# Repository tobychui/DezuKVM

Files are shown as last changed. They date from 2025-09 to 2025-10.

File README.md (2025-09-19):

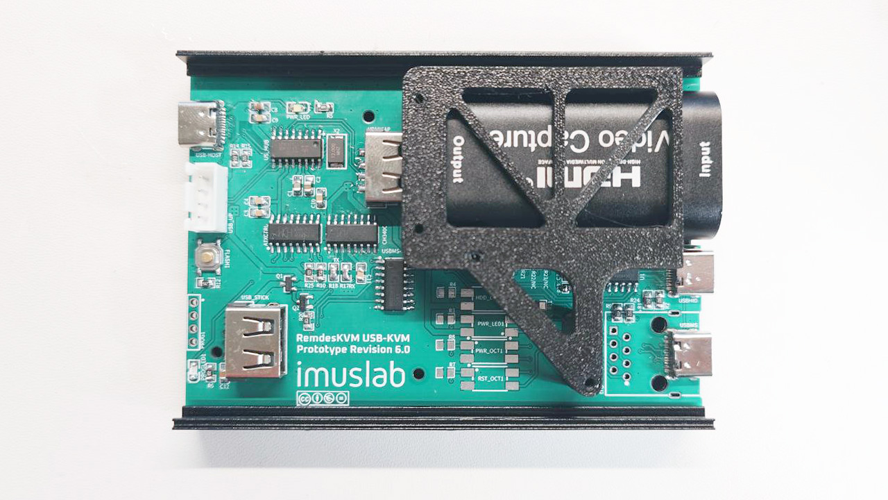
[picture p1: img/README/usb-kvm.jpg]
usb-kvm


# RemdesKVM

Budget IP-KVM designed for my SFF homelab / minilab setup.  I build this just because I don't really trust those off-the-shelf KVMs and Pi-KVM is a bit too expensive if I want to have one KVM device per computer in my homelab cluster. 

> [!WARNING]
> This project is in its very early stage and not production ready. Use with your own risk. 

## Build

### Remdeskd (RemdesKVM daemon)

The Remdeskd is a golang written piece of code that runs on a x86 or ARM computer with Debian based Linux installed. Require v4l2 and alsa with kernel 6.1 or above.  

To build the Remdeskd, you will need go compiler. The go package manager will take care of the dependencies during your first build. 

```bash
cd remdeskd/
go mod tidy
go build

sudo ./remdeskd
# or use ./remdeskd -h to show all start options
```

(Setup the remdeskd as systemd service instruction will be added later)

#### Uskvm (IP-KVM firmware)

The usbkvm is developed with Arduino IDE. You will need the [ch55xduino broad API](https://github.com/DeqingSun/ch55xduino) installed in order to compile and flash the firmware to the USB-KVM hardware.

For first time flashing the firmware, **follow the steps below carefully**.

1. Prepare the firmware code in your Arduino
2. Press compile button and wait for the compiled binary get cached (to speed up the flash process)
3. Hold down the FLASH button on the USB-KVM PCB. **Do not release it until you are told to do so.**
4. Insert the USB cable into the USB-KVM host side port and connect it to your computer. You should see multiple device pops up in your device manager. If all parts are soldered correctly, you will see a USB hub with 3 devices under it, the USB capture card (which provide a video and audio device file), a USB to UART adapter and an unknown device. That Unknown device is our CH552g (without firmware)
5. Press the upload button in your Arduino IDE with no serial port selected
6. **Just after the code compiled, immediately release the FLASH button** (Notes: if you do this too slow, you will get a timeout in your Arduino IDE console. If you release too early, the MCU will reset itself and back to runtime mode. Try a few time if you keep having issues with this step)
7.  After the firmware upload, you should see a Serial device pop up in your device manager and the unknown device is gone. 

For future firmware re-flash or update, simply upload using the serial port like an ordinary Arduino dev board. 

## Architecture

The RemdesKVM project divides into two subsystems

1. IP-KVM Host software (running on x86 / ARM computer with USB host port)
2. USB-KVM Hardware and firmware (connect to KVM-host using USB)

Each of the parts can be used independently with or without the other part of the system.  For example, you can use the IP-KVM Host software with off-the-shelf USB-KVM that uses the same chipset used in the RemdesKVM USB-KVM device, or you can use the USB-KVM hardware and firmware on a Raspberry Pi with other KVM host software (with limited functionality). 

### Project Structure

- models -- 3D models files for 3D printing
- pcbs -- PCB gerber and schematics 
- remdeskd -- RemdesKVM Daemon, running on the IP-KVM host ARM SBC
- usbkvm -- Firmware for RemdesKVM USB-KVM on board MCU (Ch552g)

**Note: There will be no support if you are using 3rd party parts or systems. If you are creating a new issue, make sure you are using the official implementation here with the recommended hardware and software setups**

### Part List

## Change Log

Change log for USB-KVM hardware design

| Version | Changes | Issues |
| --- | --- | --- |
| v1.0 - v2.0 | Concept prototypes | - |
| v3.0 | Reduce complexity | HDMI child board not working |
| v4.0 | Restructure board form factor | CH552G do not handle UART signal fast enough for cursor movements |
| v5.0 | Added USB mass storage port and dedicated USB UART chip for UART to HID chip communication | USB mass storage power switch causes overcurrent on USB VBUS line and resets the whole bus |

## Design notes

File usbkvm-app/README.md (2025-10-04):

# USB-KVM App

A USB-KVM application that runs on your laptop / PC that provide an interface for using the USB-KVM device.

**This is the off-grid version of DezuKVM and only provide a subset of features that the full DezuKVM IP-KVM has to offer. This is mostly for local debugging or as a temporary display / keyboard & mouse for server management. **

## Hosting

### Self-hosted Site with HTTPS

Since the USB-KVM app is simply a webpage, if you already got a server with proper HTTPS setup, you can just rename & place the whole `./www/` folder into your web server and launch the index.html on your laptop that has the USB-KVM device connected. 

### Run USB-KVM App Offline / Without external web server

If you do not have a HTTPS web server already running in your homelab or you want to use the USB-KVM offline, you can use the simple HTTPS server provided here to serve the site wit ha self-signed certificate.

```
go mod tidy
go build
./usbkvm
```

This will automatically generate the `cert.pem` and `key.pem` file for the TLS connection and you can visit the self-hosted USB-KVM App user interface by opening `https://localhost:8443` using Chrome (or any Chromium based) browser.

*Note: Firefox do not support Web Serial API, so until Firefox support this API, you will not be able to use this with Firefox Browser.*

## Usage

1. Connect the DezuKVM USB-KVM device to your laptop via the host side USB port
2. Connect the remote server / computer that you want to control to the DezuKVM USB-KVM device via the HDMI port and the USB port. 
3. Start USB-KVM app on your laptop. Since all the operations and logic are written on the front-end page, you can either load it from a remote or local web server, as soon as there are **HTTS** it will work.
4. Select the video capture device, it usually shows up as USB Video
5. (Optional) Select the audio capture device, it usually show up as USB Digital Audio
6. Click the keyboard icon and select the USB UART interface that connects to the CH9329 keyboard HID chip. There are two serial devices on the DezuKVM device and the USB UART one are for KVM and the CDC device are for the onboard auxiliary MCU (the AuxMCU is not used in this setup. See dezukvmd for more details on how it is used)
7. If everything works correctly, you should be able to see your remote computer video and audio output on your browser tab, as well as moving the remote cursor with your local mouse.

## Screenshots

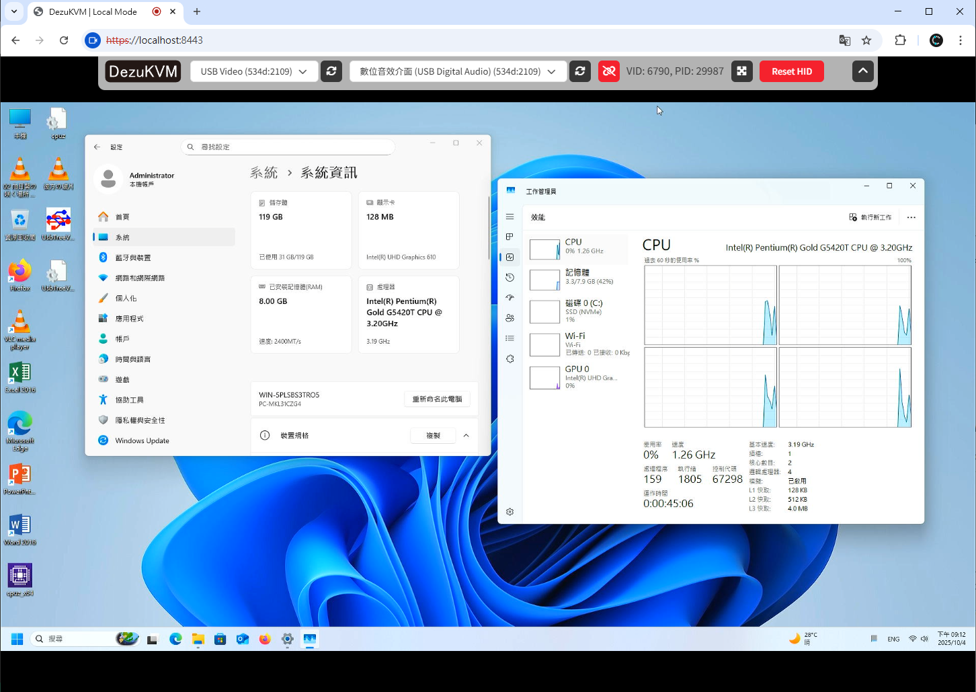
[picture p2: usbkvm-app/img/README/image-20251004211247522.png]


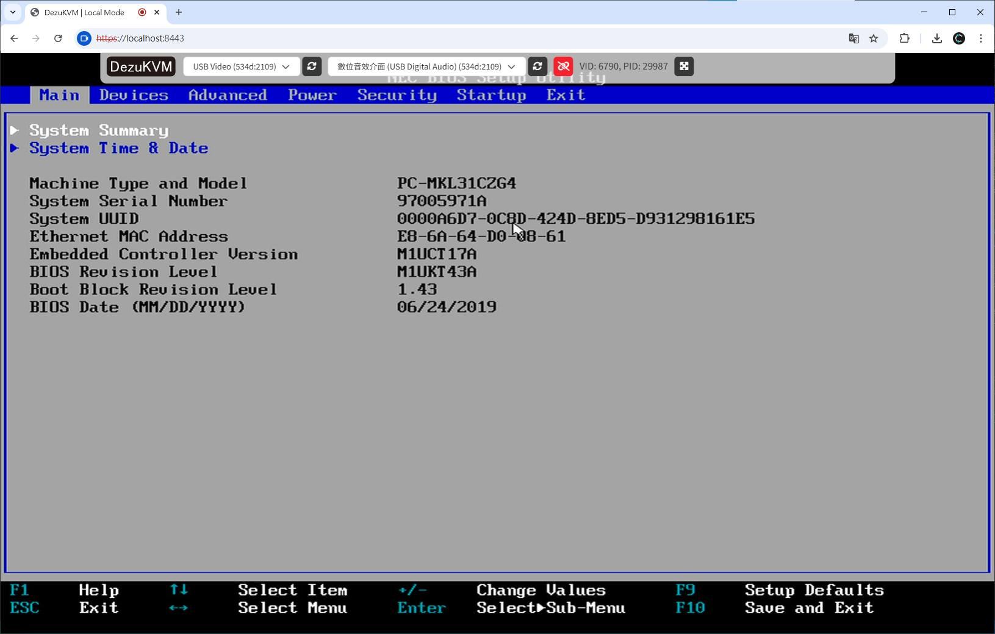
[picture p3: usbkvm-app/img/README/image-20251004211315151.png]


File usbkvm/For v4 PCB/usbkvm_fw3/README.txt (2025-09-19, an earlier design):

By default the CH9329 uses 9600 baudrate to communicate with MCU
However, this might significantly reduce the fps of the cursor
If you want a smoother cursor experience, follow the steps below to configure
the CH9329 to use a higher baudrate to communicate with CH552G

1. Flash the CH552G with Serial0 9600 baudrate to act as a USB to UART converter
2. Plug in the CH9239 port to your slave computer so it get power
3. Use the remdeskvmd -mode=cfgchip command to set the baudrate to 19200
4. Disconnect the CH9329 KVM port that also power down the CH9329
5. Flash the CH552G with Serial0 updated to 19200 baudrate
6. Repower the CH9329, now CH552G shd be able to communicate with it using 19200 baudrate

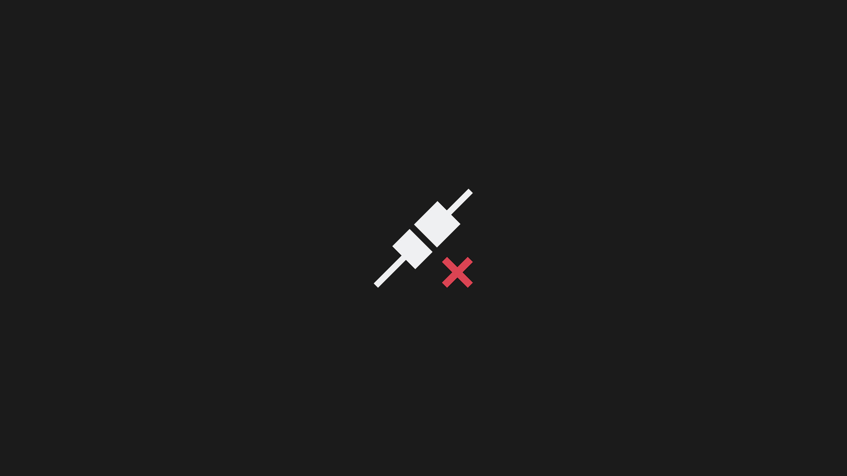
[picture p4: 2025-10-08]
dezukvmd/mod/usbcapture/stream_takeover.jpg

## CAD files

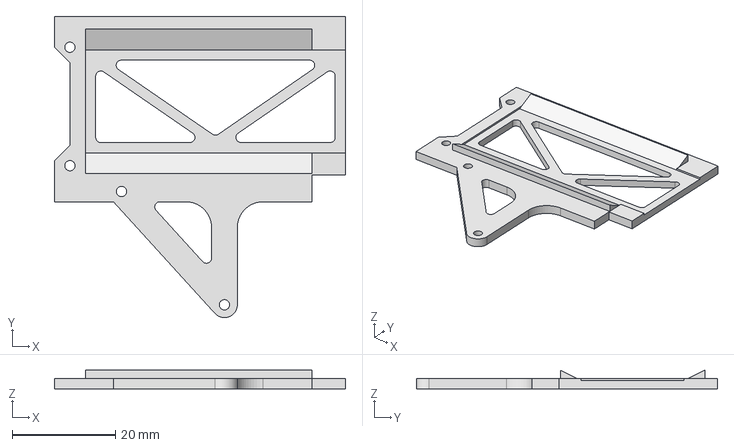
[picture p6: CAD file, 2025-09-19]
models/hdmi-capture-holder/capture_holder_bottom.stp
56.5 x 58.5 x 3.60 mm

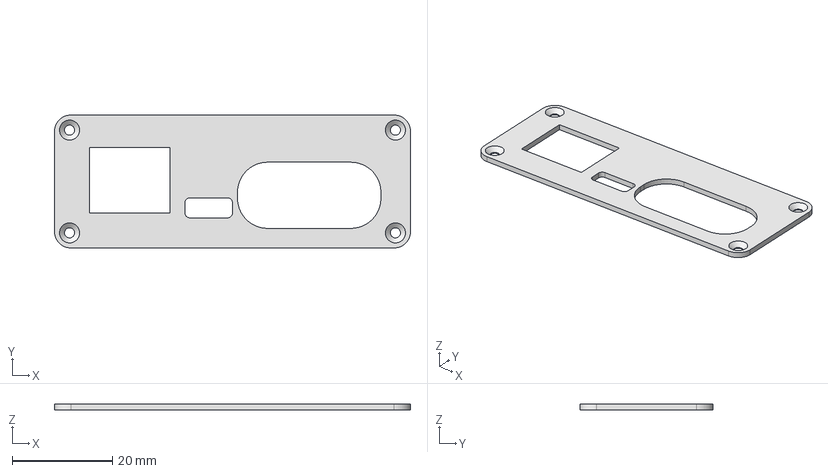
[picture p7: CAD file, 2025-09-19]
models/usb-kvm-case/cover-slave.stp
71.0 x 26.5 x 1.20 mm

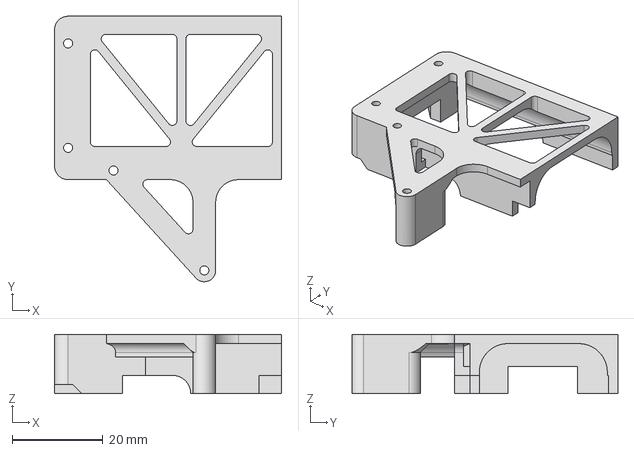
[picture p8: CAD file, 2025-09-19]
models/hdmi-capture-holder/capture_holder_top.stp
50.0 x 58.5 x 13.0 mm

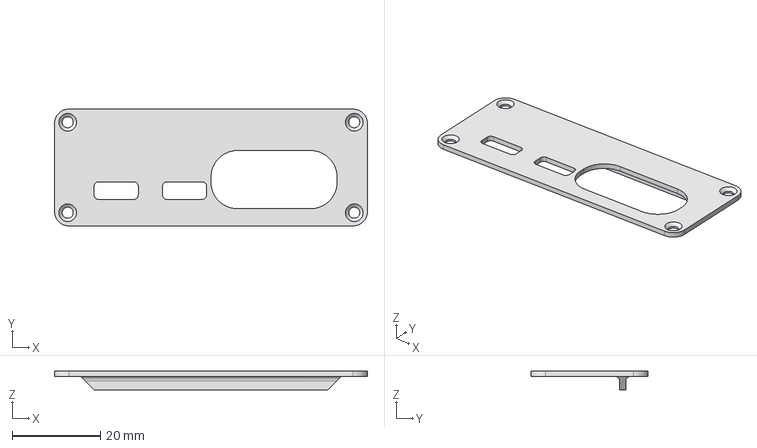
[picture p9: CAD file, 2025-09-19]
models/usb-kvm-case/cover-slave-usbms.stp
71.0 x 26.5 x 4.20 mm

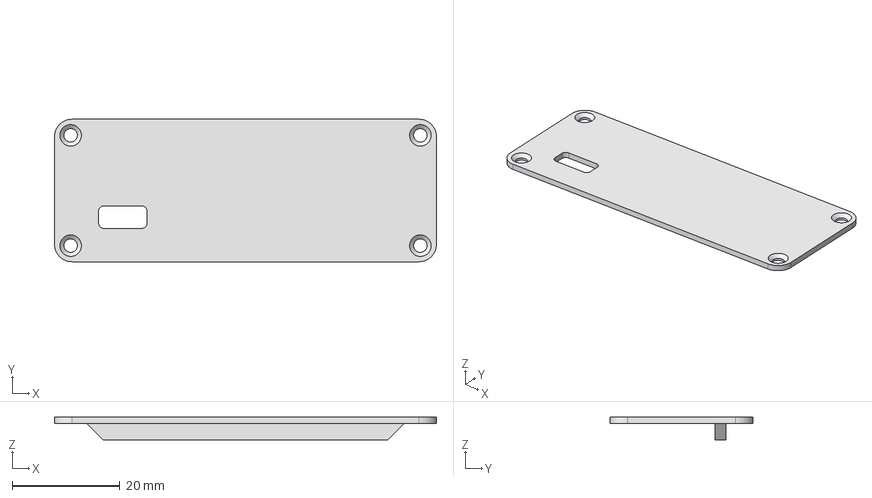
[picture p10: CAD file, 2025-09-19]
models/usb-kvm-case/cover.stp
71.0 x 26.5 x 4.20 mm

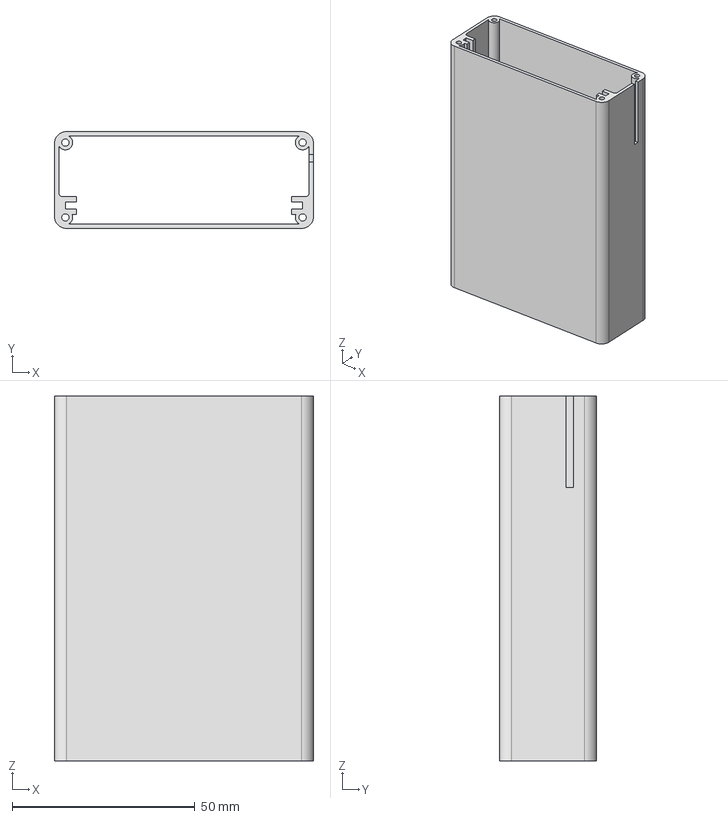
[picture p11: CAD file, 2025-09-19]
models/usb-kvm-case/case.stp
71.0 x 26.5 x 100.0 mm

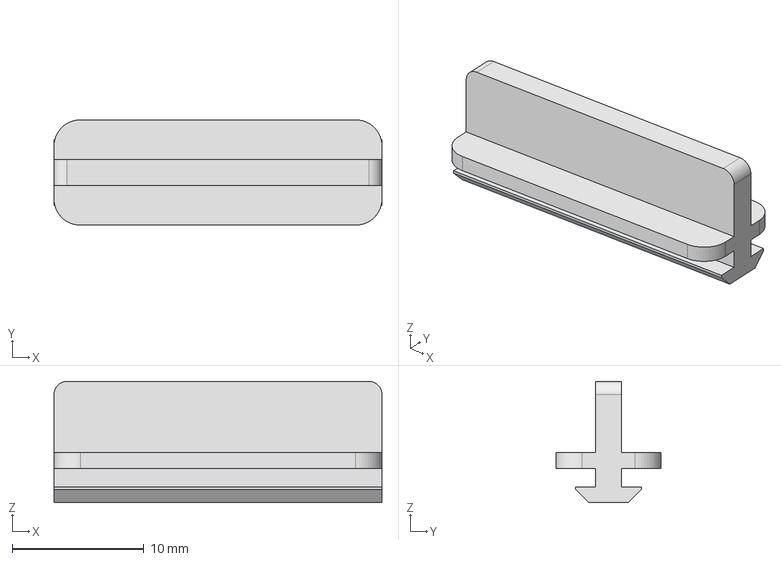
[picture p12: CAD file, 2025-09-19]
models/usb-kvm-case/flag.stp
24.9 x 8.00 x 9.20 mm

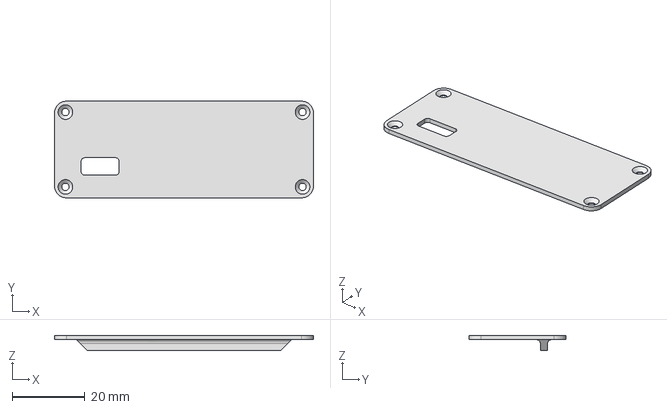
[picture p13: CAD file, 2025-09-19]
models/usb-kvm-case/cover-usb-ms.stp
71.0 x 26.5 x 4.20 mm

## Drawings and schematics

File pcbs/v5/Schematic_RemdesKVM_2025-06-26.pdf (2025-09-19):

## Upstream USB Port Power Ripple Filter

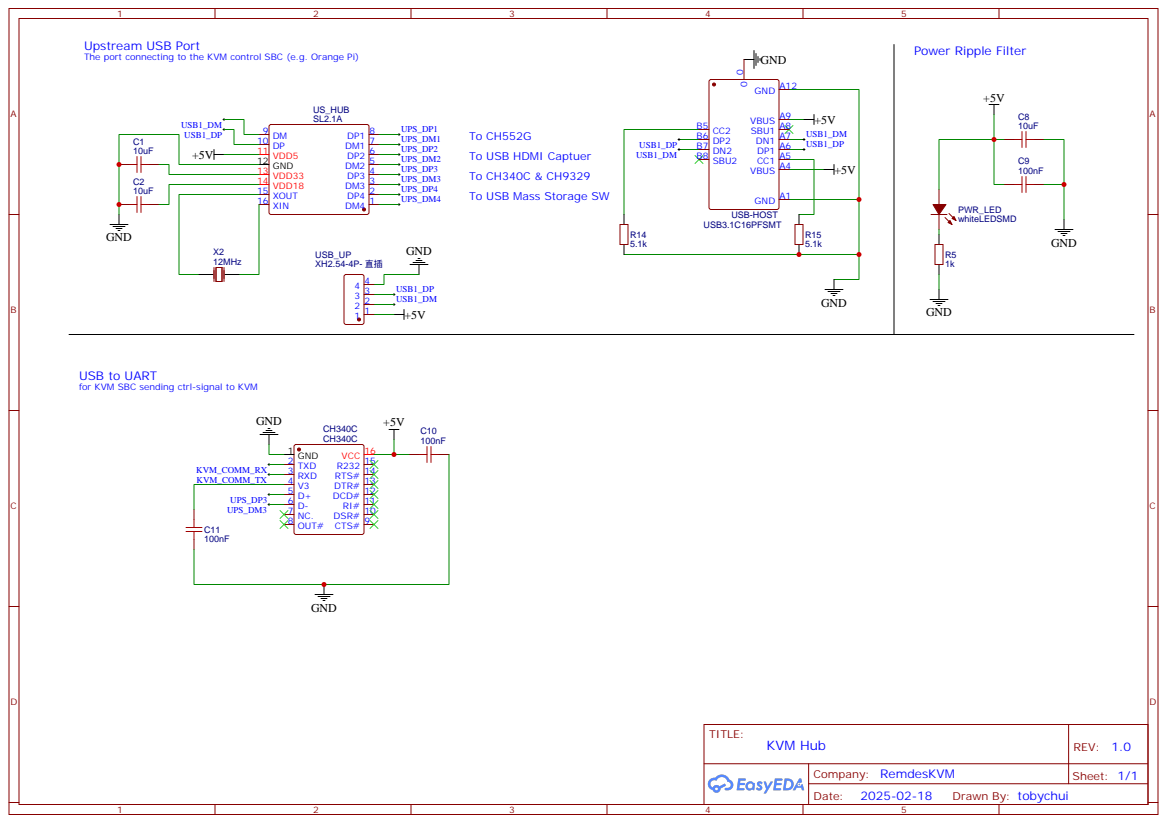
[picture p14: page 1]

The port connecting to the KVM control SBC (e.g. Orange Pi)

To USB HDMI Captuer
To USB Mass Storage SW

USB to UART
for KVM SBC sending ctrl-signal to KVM

DSR# 10 RI# 11 DCD# 12 DTR# 13 RTS# 14 R232 15 VCC 16

## USB HDMI Capture Card

# DEF 10 SET 11 UD+ 12 UD- 13 GND 14 VCC 15 V33 16

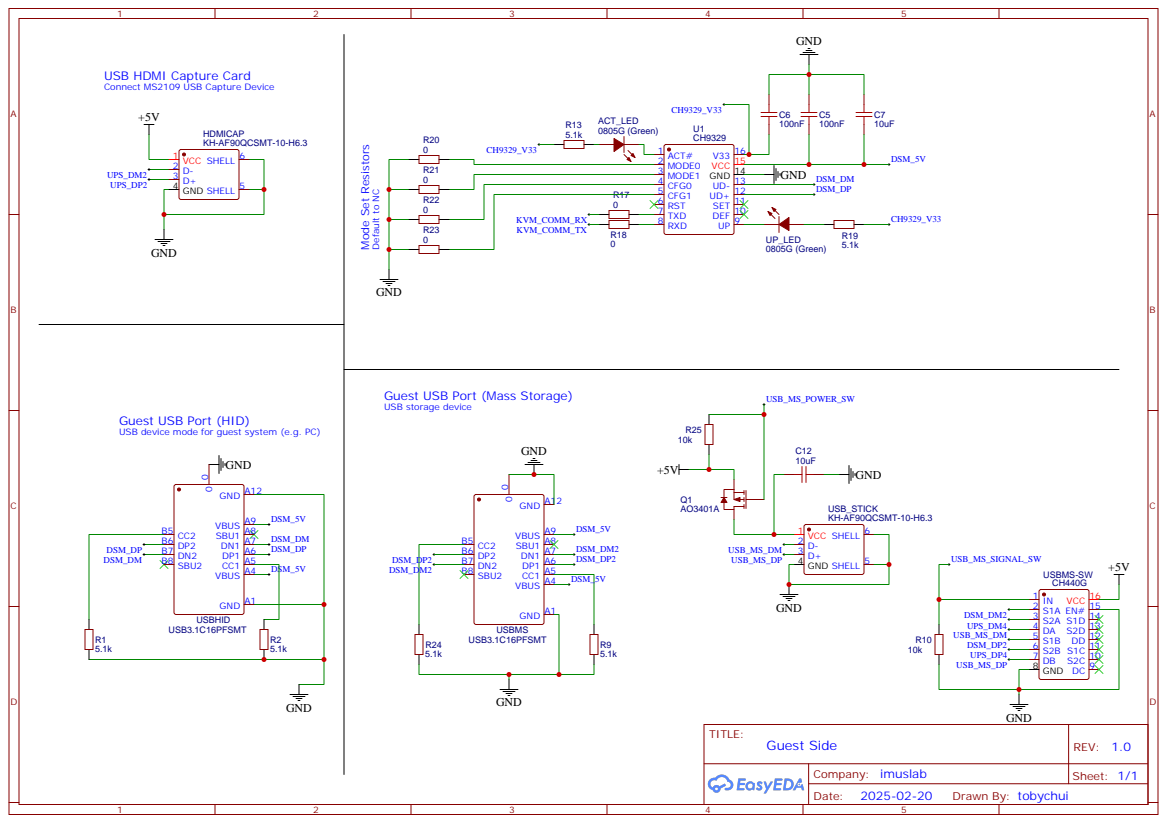
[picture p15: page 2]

Connect MS2109 USB Capture Device

Guest USB Port (Mass Storage)
USB storage device

Guest USB Port (HID)
USB device mode for guest system (e.g. PC)

## ATX Power Control

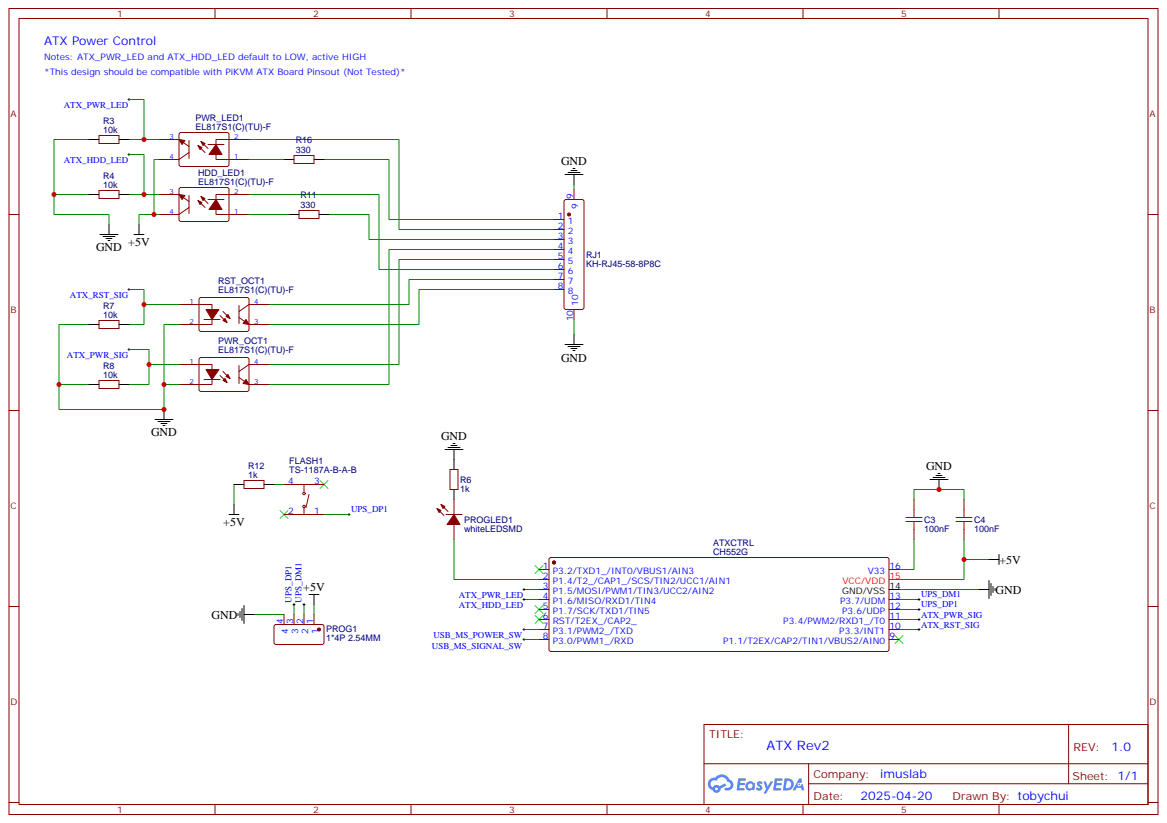
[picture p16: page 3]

Notes: ATX_PWR_LED and ATX_HDD_LED default to LOW, active HIGH
*This design should be compatible with PiKVM ATX Board Pinsout (Not Tested)*

P3.3/INT1 10 P3.4/PWM2/RXD1_/T0 11 P3.6/UDP 12 P3.7/UDM 13 GND/VSS 14 VCC/VDD 15 V33 16

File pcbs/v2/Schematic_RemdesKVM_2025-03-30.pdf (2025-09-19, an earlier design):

## Upstream USB Port Power Ripple Filter

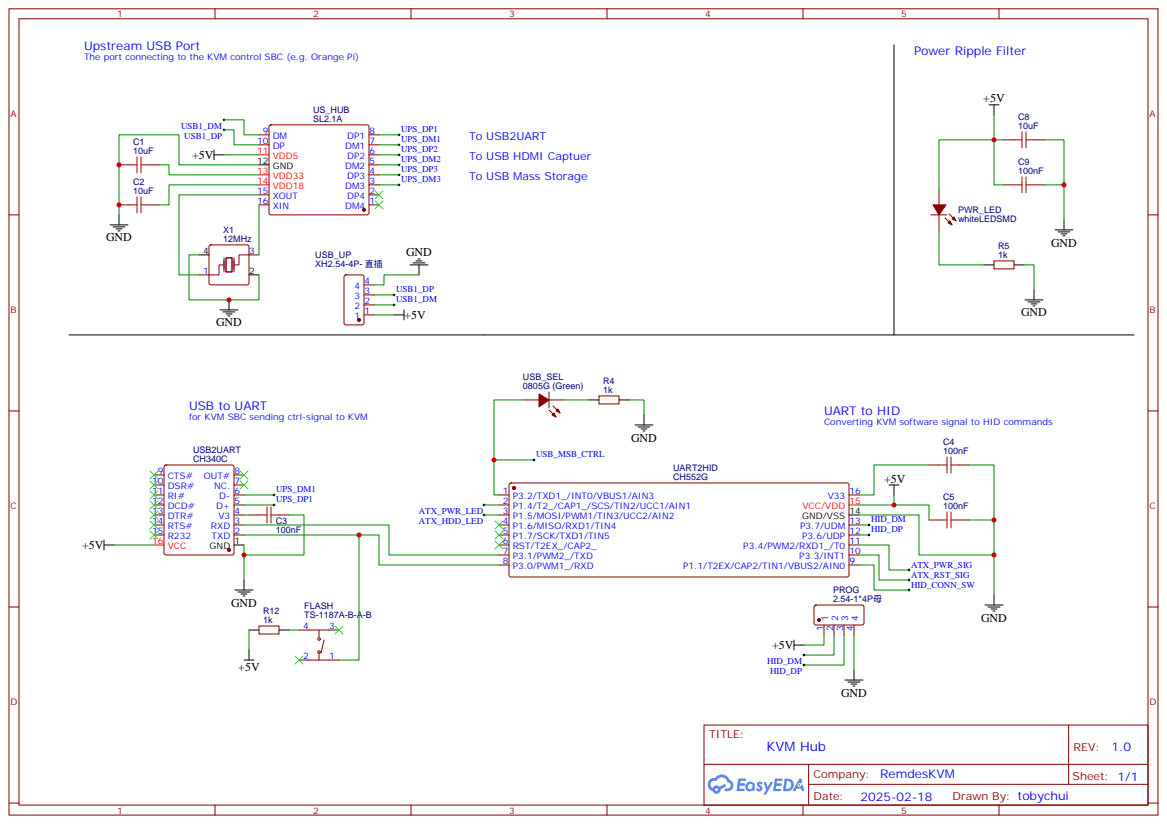
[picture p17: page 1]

The port connecting to the KVM control SBC (e.g. Orange Pi)

To USB2UART
To USB HDMI Captuer
To USB Mass Storage

USB to UART
for KVM SBC sending ctrl-signal to KVM

UART to HID
Converting KVM software signal to HID commands

P3.3/INT1 10 P3.4/PWM2/RXD1_/T0 11 P3.6/UDP 12 P3.7/UDM 13 GND/VSS 14 VCC/VDD 15 V33 16

## USB HDMI Capture Card USB HID Downstream Switch

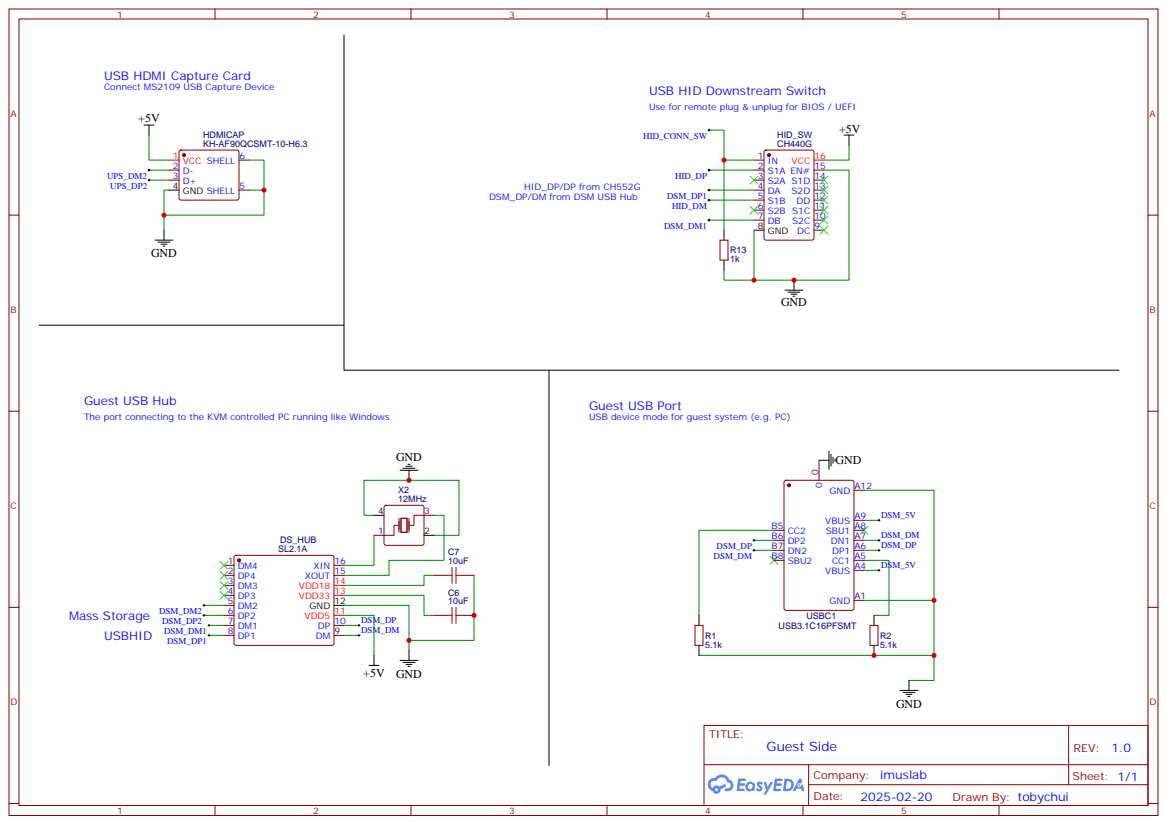
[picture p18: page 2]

Connect MS2109 USB Capture Device

Use for remote plug & unplug for BIOS / UEFI

DSM_DP/DM from DSM USB Hub

## ATX Power Control

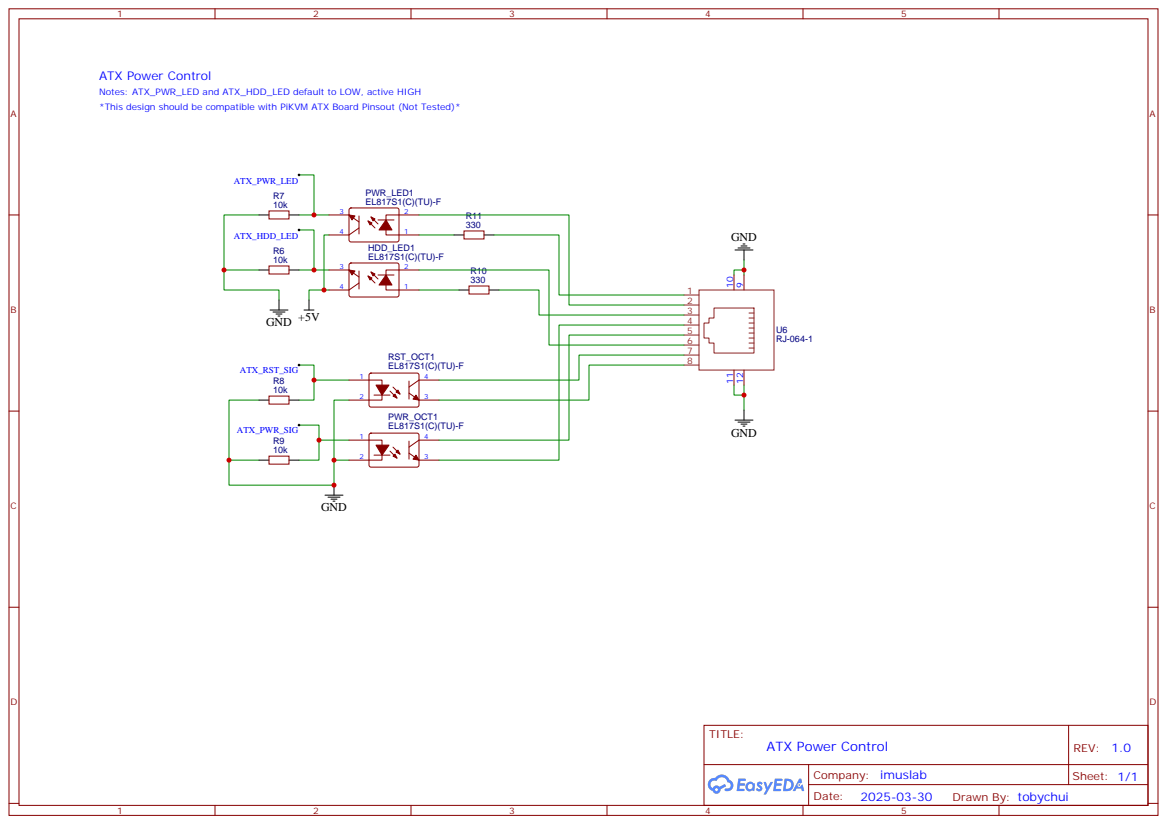
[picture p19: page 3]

Notes: ATX_PWR_LED and ATX_HDD_LED default to LOW, active HIGH
*This design should be compatible with PiKVM ATX Board Pinsout (Not Tested)*

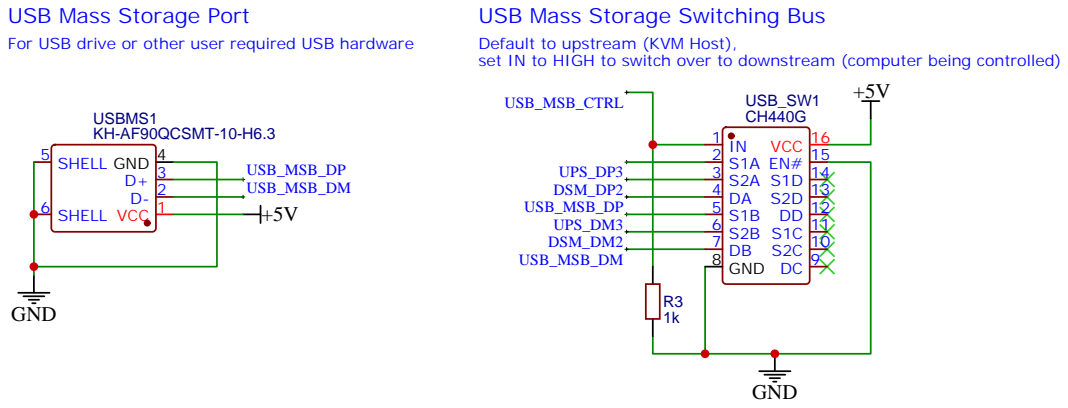
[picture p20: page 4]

USB Mass Storage Port
For USB drive or other user required USB hardware

USB Mass Storage Switching Bus
Default to upstream (KVM Host),
set IN to HIGH to switch over to downstream (computer being controlled)

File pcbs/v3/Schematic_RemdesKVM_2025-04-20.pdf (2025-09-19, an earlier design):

## Upstream USB Port Power Ripple Filter

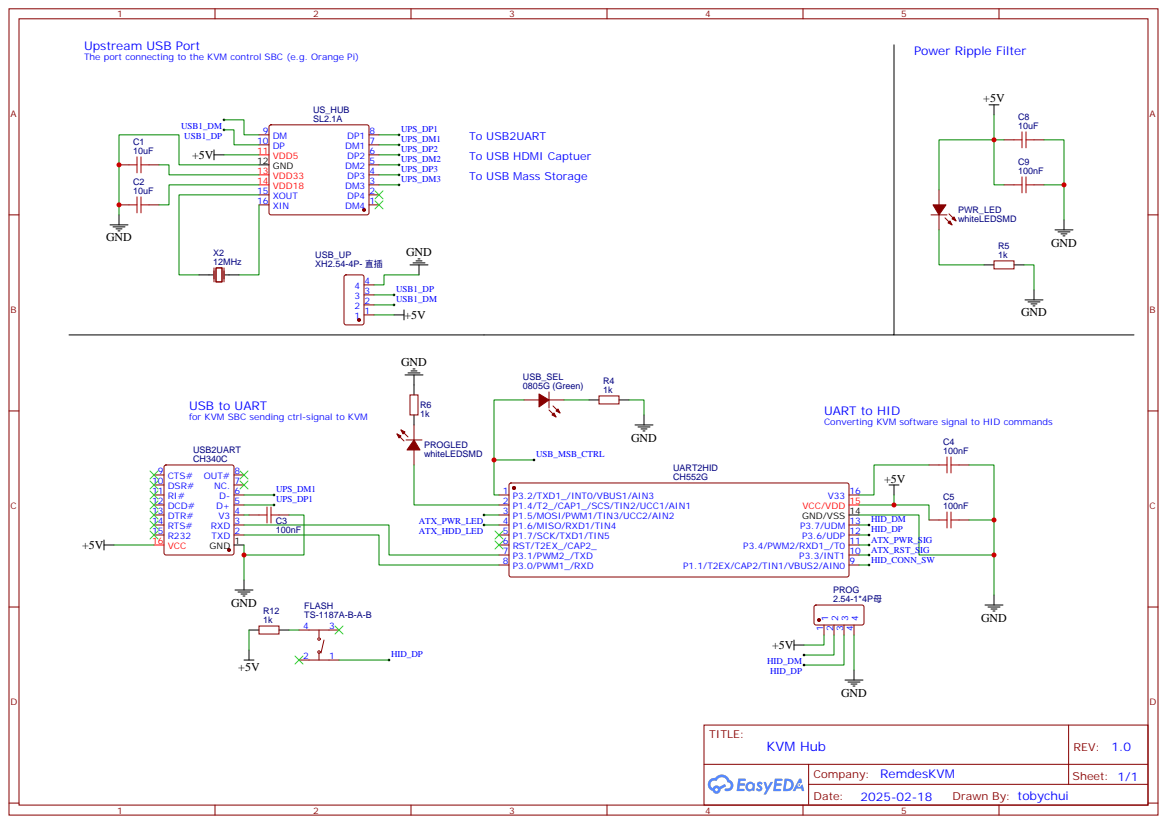
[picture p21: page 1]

The port connecting to the KVM control SBC (e.g. Orange Pi)

To USB2UART
To USB HDMI Captuer
To USB Mass Storage

USB to UART
for KVM SBC sending ctrl-signal to KVM

UART to HID
Converting KVM software signal to HID commands

P3.3/INT1 10 P3.4/PWM2/RXD1_/T0 11 P3.6/UDP 12 P3.7/UDM 13 GND/VSS 14 VCC/VDD 15 V33 16

## USB HDMI Capture Card USB HID Downstream Switch

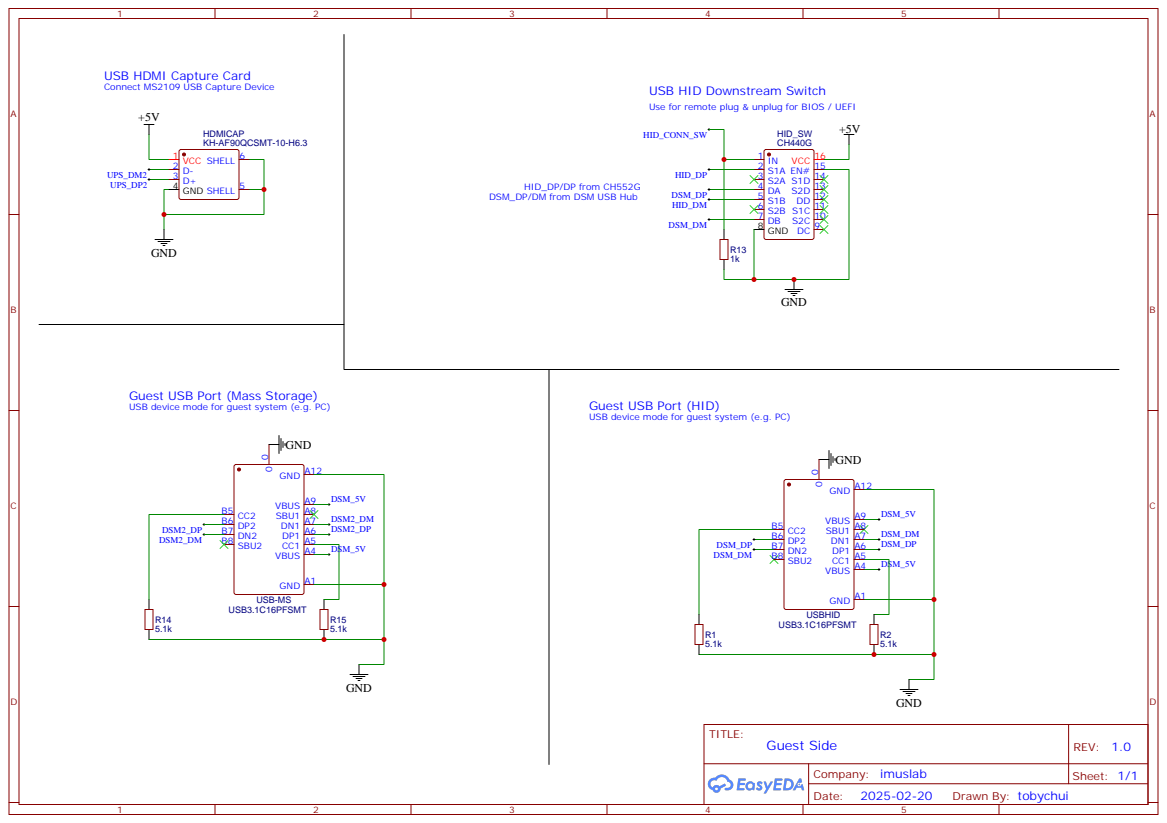
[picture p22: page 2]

Connect MS2109 USB Capture Device

Use for remote plug & unplug for BIOS / UEFI

DSM_DP/DM from DSM USB Hub

Guest USB Port (Mass Storage)
USB device mode for guest system (e.g. PC)

Guest USB Port (HID)

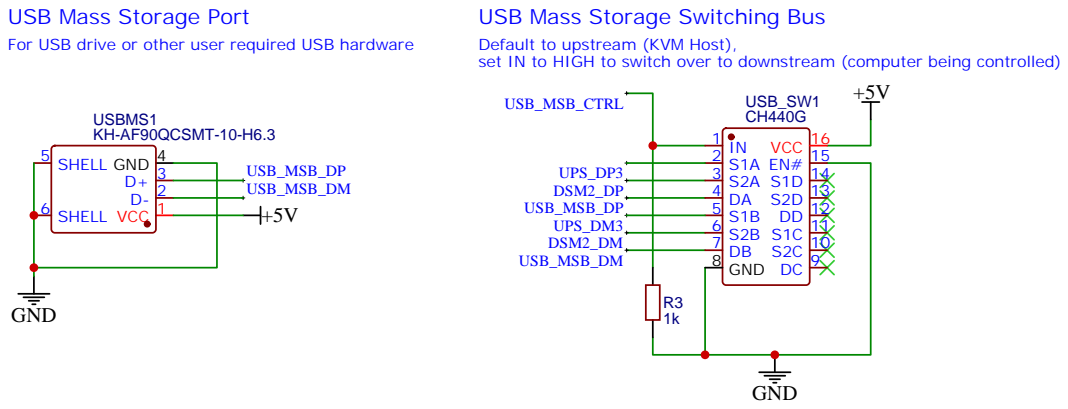
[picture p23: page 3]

USB Mass Storage Port
For USB drive or other user required USB hardware

USB Mass Storage Switching Bus
Default to upstream (KVM Host),
set IN to HIGH to switch over to downstream (computer being controlled)

## ATX Power Control

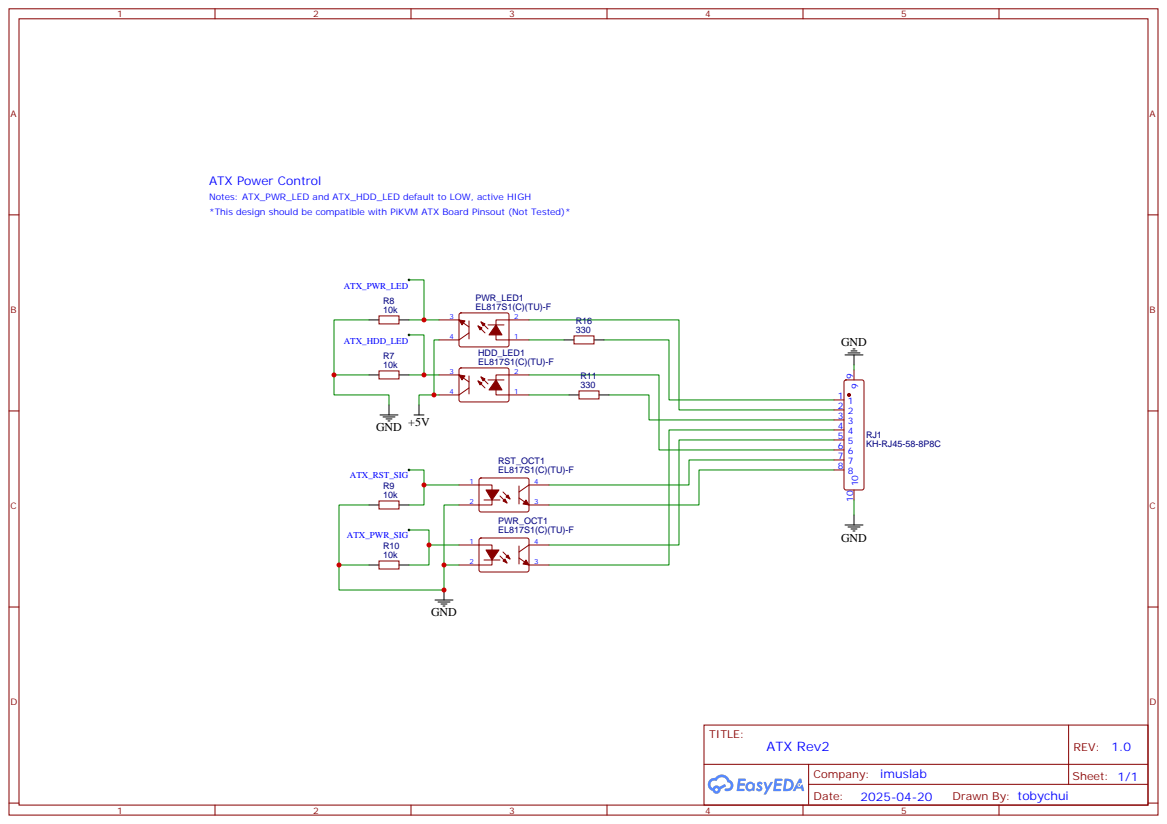
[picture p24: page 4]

Notes: ATX_PWR_LED and ATX_HDD_LED default to LOW, active HIGH
*This design should be compatible with PiKVM ATX Board Pinsout (Not Tested)*

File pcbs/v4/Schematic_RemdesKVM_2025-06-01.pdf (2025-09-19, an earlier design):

## Upstream USB Port Power Ripple Filter

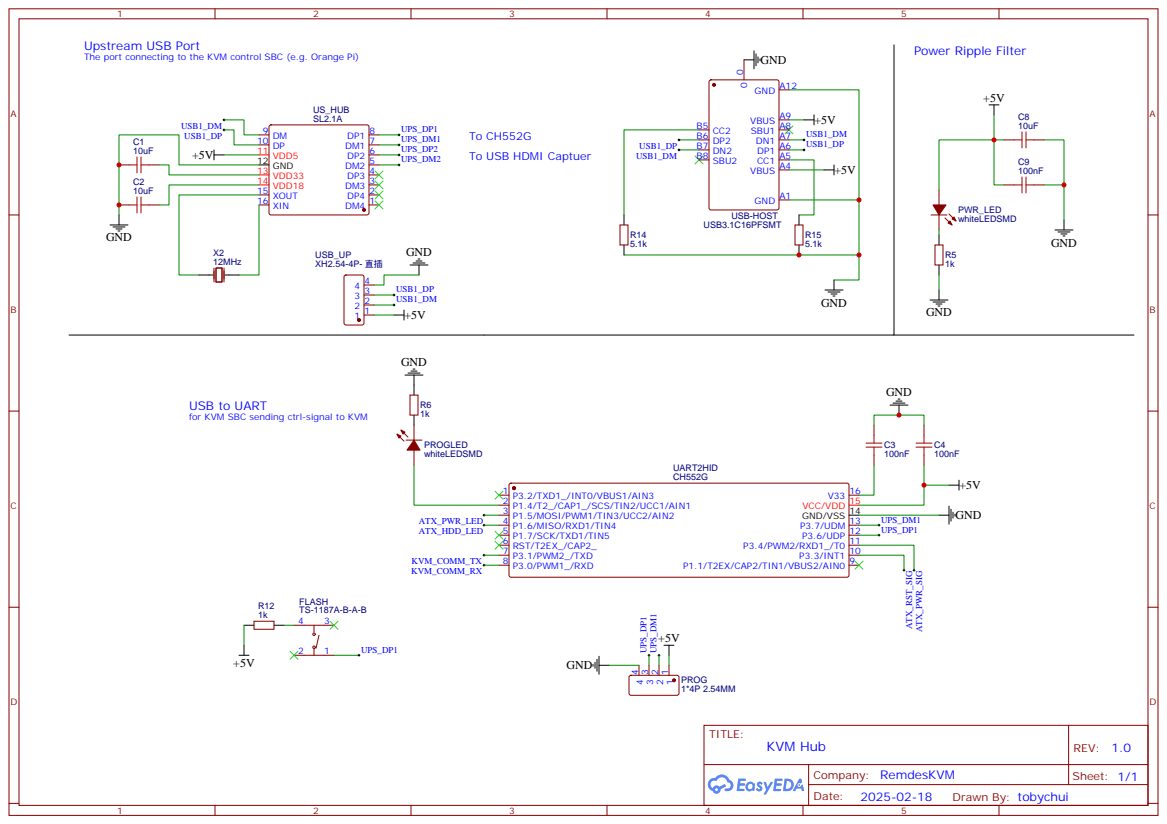
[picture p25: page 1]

The port connecting to the KVM control SBC (e.g. Orange Pi)

To USB HDMI Captuer

USB to UART
for KVM SBC sending ctrl-signal to KVM

P3.3/INT1 10 P3.4/PWM2/RXD1_/T0 11 P3.6/UDP 12 P3.7/UDM 13 GND/VSS 14 VCC/VDD 15 V33 16

## USB HDMI Capture Card

# DEF 10 SET 11 UD+ 12 UD- 13 GND 14 VCC 15 V33 16


Connect MS2109 USB Capture Device

Guest USB Port (HID)
USB device mode for guest system (e.g. PC)

## ATX Power Control


Notes: ATX_PWR_LED and ATX_HDD_LED default to LOW, active HIGH
*This design should be compatible with PiKVM ATX Board Pinsout (Not Tested)*

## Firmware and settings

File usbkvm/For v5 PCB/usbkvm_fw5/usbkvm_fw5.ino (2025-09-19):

/*
  RemdesKVM USB-KVM
  Firmware for PCB design v5

  Author: tobychui

  Upload Settings
  CH552G  
  24Mhz (Internal)
*/
#include <Serial.h>

/* Build flags */
#define ENABLE_DEBUG 1  //Enable debug print to Serial, do not use this in IP-KVM setup

/* Enums */
#define USB_MS_SIDE_KVM_HOST 0
#define USB_MS_SIDE_REMOTE_PC 1

/* Pins definations */
#define LED_PROG 14
#define ATX_PWR_LED 15
#define ATX_HDD_LED 16
#define ATX_RST_BTN 33
#define ATX_PWR_BTN 34
#define USB_MS_PWR 31  //Active high, set to HIGH to enable USB 5V power and LOW to disable
#define USB_MS_SW 30   //LOW = remote computer, HIGH = KVM

/* Runtime defs */
#define USB_PWR_SW_PWR_DELAY 100  //ms
#define USB_PWR_SW_DATA_DELAY 10  //ms

/* Runtime variables */
uint8_t atx_status[2] = { 0, 0 };  //PWR LED, HDD LED
uint8_t usb_ms_side = 1;           //0 = KVM Controller, 1 = Computer being controlled
char c;
int led_tmp;
bool led_status = true;  //Default LED PROG state is high, on every command recv it switch state

void update_atx_led_status() {
  led_tmp = digitalRead(ATX_PWR_LED);
  atx_status[0] = led_tmp;
  led_tmp = digitalRead(ATX_HDD_LED);
  atx_status[1] = led_tmp;
}

void switch_usbms_to_kvm() {
  if (usb_ms_side == USB_MS_SIDE_KVM_HOST) {
    //Already on the KVM side
    return;
  }

#if ENABLE_DEBUG == 1
  USBSerial_println("[DEBUG] Switching USB Mass Storage node to KVM host side");
#endif
  //Disconnect the power to USB
  digitalWrite(USB_MS_PWR, LOW);
  delay(USB_PWR_SW_PWR_DELAY);

  //Switch over the device
  digitalWrite(USB_MS_PWR, HIGH);
  delay(USB_PWR_SW_DATA_DELAY);
  digitalWrite(USB_MS_SW, HIGH);
  usb_ms_side = USB_MS_SIDE_KVM_HOST;
}

void switch_usbms_to_remote() {
  if (usb_ms_side == USB_MS_SIDE_REMOTE_PC) {
    //Already on Remote Side
    return;
  }

#if ENABLE_DEBUG == 1
  USBSerial_println("[DEBUG] Switching USB Mass Storage node to remote computer side");
#endif
  //Disconnect the power to USB
  digitalWrite(USB_MS_PWR, LOW);
  delay(USB_PWR_SW_PWR_DELAY);

  //Switch over the device
  digitalWrite(USB_MS_PWR, HIGH);
  delay(USB_PWR_SW_DATA_DELAY);
  digitalWrite(USB_MS_SW, LOW);
  usb_ms_side = USB_MS_SIDE_REMOTE_PC;
}

void report_status() {
  //Report status of ATX and USB mass storage switch in 1 byte
  //Bit 0: PWR LED status
  //Bit 1: HDD LED status
  //Bit 2: USB Mass Storage mounted side
  //Bit 3 - 7: Reserved
  uint8_t status = 0x00;
  status |= (atx_status[0] & 0x01);
  status |= (atx_status[1] & 0x01) << 1;
  status |= (usb_ms_side & 0x01) << 2;
#if ENABLE_DEBUG == 1
  USBSerial_print("[DEBUG] ATX State");
  USBSerial_print("PWR=");
  USBSerial_print(atx_status[0]);
  USBSerial_print(" HDD=");
  USBSerial_print(atx_status[1]);
  USBSerial_print(" USB_MS=");
  USBSerial_println(usb_ms_side);
#endif
  USBSerial_print(status);
}

void execute_cmd(char c) {
  switch (c) {
    case '1':
      //Press down the power button
      digitalWrite(ATX_PWR_BTN, HIGH);
      break;
    case '2':
      //Release the power button
      digitalWrite(ATX_PWR_BTN, LOW);
      break;
    case '3':
      //Press down the reset button
      digitalWrite(ATX_RST_BTN, HIGH);
      break;
    case '4':
      //Release the reset button
      digitalWrite(ATX_RST_BTN, LOW);
      break;
    case '5':
      //Switch USB mass storage to KVM side
      switch_usbms_to_kvm();
      break;
    case '6':
      //Switch USB mass storage to remote computer
      switch_usbms_to_remote();
      break;
    default:
      //Unknown command
      break;
  }
}


void setup() {
  pinMode(ATX_PWR_LED, INPUT);
  pinMode(ATX_HDD_LED, INPUT);
  pinMode(ATX_RST_BTN, OUTPUT);
  pinMode(ATX_PWR_BTN, OUTPUT);
  pinMode(USB_MS_PWR, OUTPUT);
  pinMode(USB_MS_SW, OUTPUT);
  pinMode(LED_PROG, OUTPUT);

  digitalWrite(LED_PROG, HIGH);
  digitalWrite(ATX_RST_BTN, LOW);
  digitalWrite(ATX_PWR_BTN, LOW);
  digitalWrite(USB_MS_PWR, LOW);
  digitalWrite(USB_MS_SW, LOW);

  //Blink 10 times for initiations
  for (int i = 0; i < 10; i++) {
    digitalWrite(LED_PROG, HIGH);
    delay(100);
    digitalWrite(LED_PROG, LOW);
    delay(100);
  }
  digitalWrite(LED_PROG, HIGH);
  delay(1000);
  //Switch the USB thumbnail to host
  switch_usbms_to_kvm();
}

void loop() {
  if (USBSerial_available()) {
    c = USBSerial_read();
#if ENABLE_DEBUG == 1
    USBSerial_print("[DEBUG] Serial Recv: ");
    USBSerial_println(c);
#endif
    execute_cmd(c);
    led_status = !led_status;
    digitalWrite(LED_PROG, led_status ? HIGH : LOW);
  }

  //update_atx_led_status();
  //report_status();
  delay(100);
}

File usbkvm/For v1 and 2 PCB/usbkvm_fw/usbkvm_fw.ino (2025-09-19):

/*
  RemdesKVM USB-KVM Firmware
  Author: tobychui

  This is the USB KVM part of RemdesKVM. 
  It can be used seperately as a dedicated USB-KVM 
  module as well as connected to a Linux SBC running
  remdeskvmd via a USB 2.0 connection.

  Upload Settings
  CH552G  
  24Mhz (Internal)
  USB CODE /w 148B USB RAM
*/

#ifndef USER_USB_RAM
#error "This firmware needs to be compiled with a USER USB setting"
#endif

//#define ENABLE_DEBUG_PRINT

#include "usbkvm_fw.h"
#include "src/remdesHid/USBHIDKeyboardMouse.h"


/*
  instr_count store the current read index
  index of current instruction, all instructions have 3 bytes
  byte orders as follows
  byte 0 = opr_type
  byte 1 = opr_subtype
  byte 2 = data
*/
uint8_t instr_count = 0;

/*
  opr_type defines the type of the incoming data
  for the next byte. See usbkvm_fw.h for details.
*/
uint8_t opr_type = 0x00;

/*
  opr_subtype defines the sub-type of the operation
  Based on opr_type, there will be different catergory
  of operations. However, 0x00 is always reserved
*/

uint8_t opr_subtype = 0x00;
uint8_t opr_payload = 0x00;

/*
  cursor_direction_data handles special subtype data
  that requires to move the cursor position
*/
uint8_t cursor_direction_data[2] = { 0x00, 0x00 };
uint8_t serial_data = 0x00;

/* Function Prototypes */
uint8_t keyboard_emulation(uint8_t, uint8_t);
uint8_t mouse_emulation(uint8_t, uint8_t);
uint8_t mouse_move(uint8_t, uint8_t, uint8_t, uint8_t);
uint8_t mouse_wheel(uint8_t, uint8_t);
uint8_t usb_switch_emulation(uint8_t, uint8_t);

/* KVM Operation Execution Catergory*/
uint8_t kvm_execute_opr() {
  switch (opr_type) {
    case OPR_TYPE_RESERVED:
      //Ping test
      return resp_ok;
    case OPR_TYPE_KEYBOARD_WRITE:
      //keyboard operations
      return keyboard_emulation(opr_subtype, opr_payload);
    case OPR_TYPE_MOUSE_WRITE:
      //mouse operations
      return mouse_emulation(opr_subtype, opr_payload);
    case OPR_TYPE_MOUSE_SCROLL:
      //mouse scroll
      //for larger scroll tilt value, use the multipler
      return mouse_wheel(opr_subtype, opr_payload);
    case OPR_TYPE_SWITCH_SET:
      //set USB signal bus switch state
      return usb_switch_emulation(opr_subtype, opr_payload);
    default:
      return resp_unknown_opr;
  }
}

void setup() {
  // Start USB HID emulation
  USBInit();

  // Start CH340 UART COM
  Serial0_begin(115200);
  // Set both USB switch to LOW
  pinMode(USB_SW_SEL, OUTPUT);
  pinMode(HID_SW_SEL, OUTPUT);
  digitalWrite(HID_SW_SEL, LOW);
  digitalWrite(USB_SW_SEL, LOW);
  delay(100);
}

void loop() {
  if (Serial0_available()) {
    serial_data = 0x00;
    serial_data = Serial0_read();

//Debug print the Serial input message
#ifdef ENABLE_DEBUG_PRINT
    Serial0_write(resp_start_of_info_msg);
    Serial0_write(serial_data);
    Serial0_write(resp_end_of_msg);
#endif

    if (serial_data == OPR_TYPE_DATA_RESET) {
      //Reset opr data
      opr_type = OPR_TYPE_RESERVED;
      opr_subtype = SUBTYPE_RESERVED;
      opr_payload = 0x00;
      instr_count = 0;
      Serial0_write(resp_ok);
    } else if (instr_count == 0) {
      //Set opr type
      opr_type = serial_data;
      instr_count++;
      Serial0_write(resp_ok);
    } else if (instr_count == 1) {
      //Set opr subtype
      opr_subtype = serial_data;
      instr_count++;
      Serial0_write(resp_ok);
    } else if (opr_type == OPR_TYPE_MOUSE_MOVE) {
      //Special case where mouse move requires 4 opcodes
      if (instr_count == 2) {
        opr_payload = serial_data;  //y-steps, reusing payload for lower memory consumption
        instr_count++;
      } else if (instr_count == 3) {
        cursor_direction_data[0] = serial_data;  //x-direction
        instr_count++;
      } else if (instr_count == 4) {
        cursor_direction_data[1] = serial_data;  //y-direction
        opr_type = OPR_TYPE_RESERVED;
        instr_count = 0;
        mouse_move(opr_subtype, opr_payload, cursor_direction_data[0], cursor_direction_data[1]);
        cursor_direction_data[0] = 0x00;
        cursor_direction_data[1] = 0x00;
        opr_subtype = 0x00;
      }
      Serial0_write(resp_ok);
    } else {
      opr_payload = serial_data;
      //Execute the kvm operation
      uint8_t err = kvm_execute_opr();
      Serial0_write(err);

      //Reset the instruction counter and ready for the next instruction
      instr_count = 0;
    }
  }
  delay(1);
}

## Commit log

2025-09-19 Init commit
    [capture_holder_bottom.stp, capture_holder_top.stp, case.stp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]
2025-10-04 Added USB-KVM client
    added offline usb-kvm test client for USB-KVM device test
